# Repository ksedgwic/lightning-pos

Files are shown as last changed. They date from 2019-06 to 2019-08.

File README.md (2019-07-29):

Lightning Pay Station
================================================================

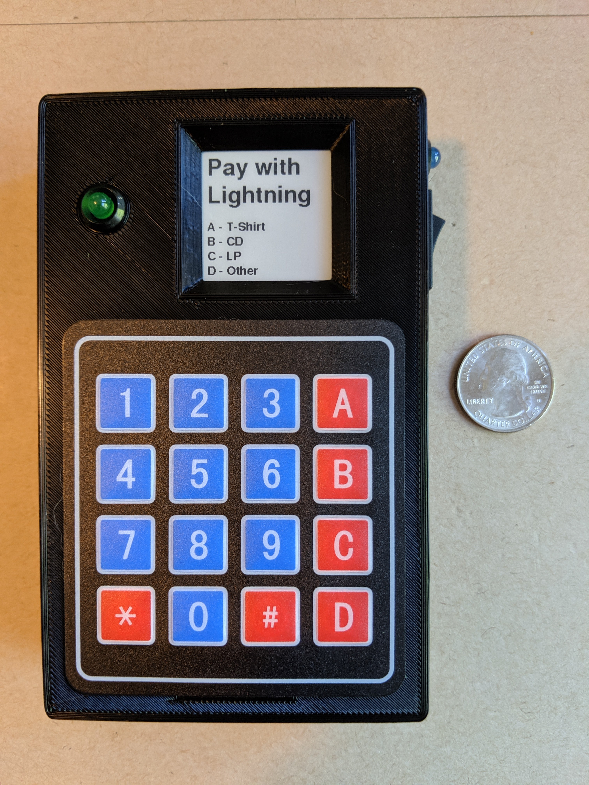
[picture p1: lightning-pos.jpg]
Lightning Pay Station


Many thanks to [arcbtc](https://github.com/arcbtc), his 
[OpenNode Tutorial](https://github.com/arcbtc/bitcoin2019conf)
and gift of working kit totally bootstrapped this project.

The goal of this project is to build an inexpensive open source
point-of-sale terminal for lightning network payments.  The
terminal can connect to:
1. OpenNode Accounts
2. BTCPay's Invoice API
3. LND's REST Interface

The unit is designed to be attached to a wall or used standalone on a
counter.  It contains an internal battery and can operate for many
hours on battery power.  It requires a WiFi network to connect to the
invoice api.

The current software supports three "presets" for commonly purchased
item descriptions and prices and an "other" item with a dynamically
specified price.

The [Parts List](parts-list.md) describes all needed parts.

The case can be 3D printed from the provided STL files.

The [Assembly Instructions](assembly.md) show how to put it together.

## Create Account at OpenNode

Create an account at [OpenNode](https://app.opennode.co/join/fad8135d-ed69-4811-840c-bfa4e30df563).

Navigate to Settings -> Integrations -> API keys.

Select "Add key" and set the permissions to "Invoices".  Make a note
of the Invoice API key string.

## Setup Arduino IDE

Start with the [SparkFun Software Setup
Directions](https://learn.sparkfun.com/tutorials/esp32-thing-plus-hookup-guide#software-setup)
to install the IDE and establish basic functionality.

Next, from "Manage Libraries" install:
```
* GxEPD2
* Arduinojson
* QRCode
* AdaFruit GFX
* Keypad
* base64
```

Install pyserial:

    pip install --user pyserial

## Compile and Upload

To configure the PoS terminal please copy config.h.template to
config.h and edit as appropriate for your setup.

Press the "Upload" button to compile and load into the Arduino.

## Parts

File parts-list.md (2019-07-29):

Lightning PoS Parts List
================================================================

| Description | Quantity | Price |
|---|---:|---:|
| [MH-ET LIVE 1.54 Inch Epaper Module](https://www.aliexpress.com/item/32915952925.html) | 1 | $12.00 |
| [16 Key Membrane Switch Keypad](https://www.aliexpress.com/item/32874565775.html) | 1 |  $0.54 |
| [SparkFun ESP32 Thing Plus](https://www.sparkfun.com/products/14689) | 1 | $20.95 |
| [Lithium Ion Battery - 2Ah](https://www.sparkfun.com/products/13855) | 1 | $12.95 |
| [LED - Basic Green 5mm](https://www.sparkfun.com/products/9592) | 1 |  $0.35 |
| [LED - Basic Blue 5mm](https://www.sparkfun.com/products/11372) | 1 |  $0.55 |
| [LED Holder - 5mm](https://www.sparkfun.com/products/11840) | 2 |  $1.00 |
| [Jumper Wires](https://www.sparkfun.com/products/12796) | 1 |  $1.95 |
| [Break Away Male Headers - Right Angle](https://www.sparkfun.com/products/553) | 1 |  $1.95 |
| [Rocker Switch](https://www.pololu.com/product/1406) | 1 |  $0.75 |
| [Flat Head Thread-Forming Screws](https://www.mcmaster.com/96068a153) | 4 |  $0.23 |
| [Phillips Rounded Head Thread-Forming Screws](https://www.mcmaster.com/99461A710) | 6 |  $1.41 |
| [Push-In Bumpers](https://www.mcmaster.com/9544k12) | 4 |  $0.30 |
| [6 ft USB A to MicroUSB B Cable](https://www.amazon.com/gp/product/B001AR6MI6) | 1 |  $6.39 |
| 3D Printed Case | 1 | |
| **TOTAL** | | $61.32 |

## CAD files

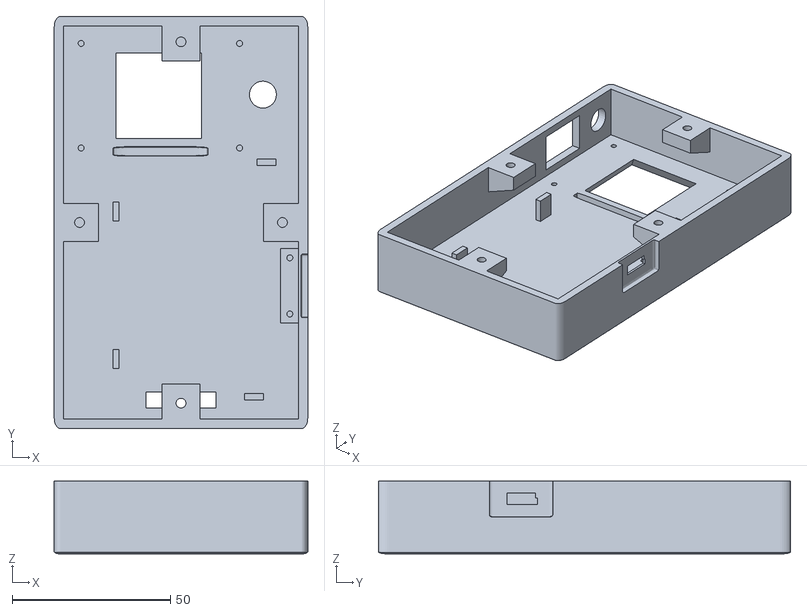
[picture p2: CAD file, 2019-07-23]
case-case.stl
80.0 x 130.0 x 23.0

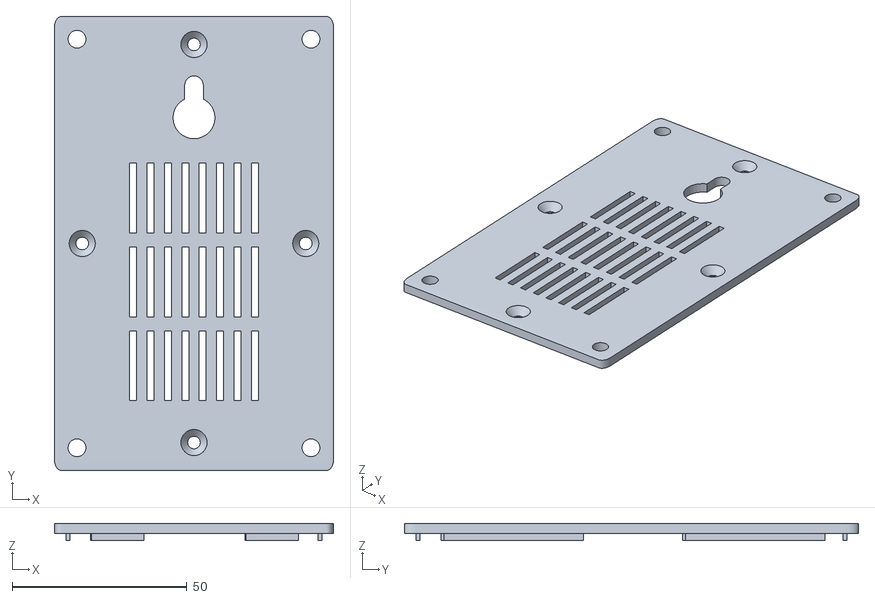
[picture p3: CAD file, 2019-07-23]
case-cover.stl
80.0 x 130.0 x 5.00

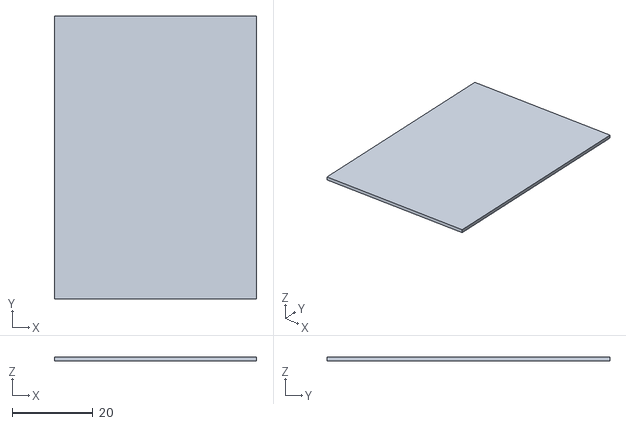
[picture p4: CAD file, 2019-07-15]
case-shield.stl
50.0 x 70.0 x 1.00

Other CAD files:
case.blend

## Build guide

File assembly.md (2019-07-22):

#### References

[ESP32 Datasheet](https://cdn.sparkfun.com/assets/learn_tutorials/8/5/2/ESP32ThingPlus_GraphicalDatasheet.pdf)

#### Split Wires

Start with this:

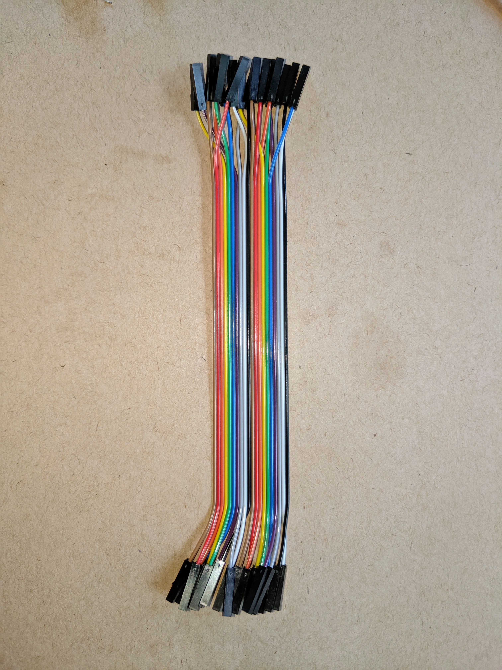
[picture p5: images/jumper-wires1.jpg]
Jumper Wires 1


End up with this:

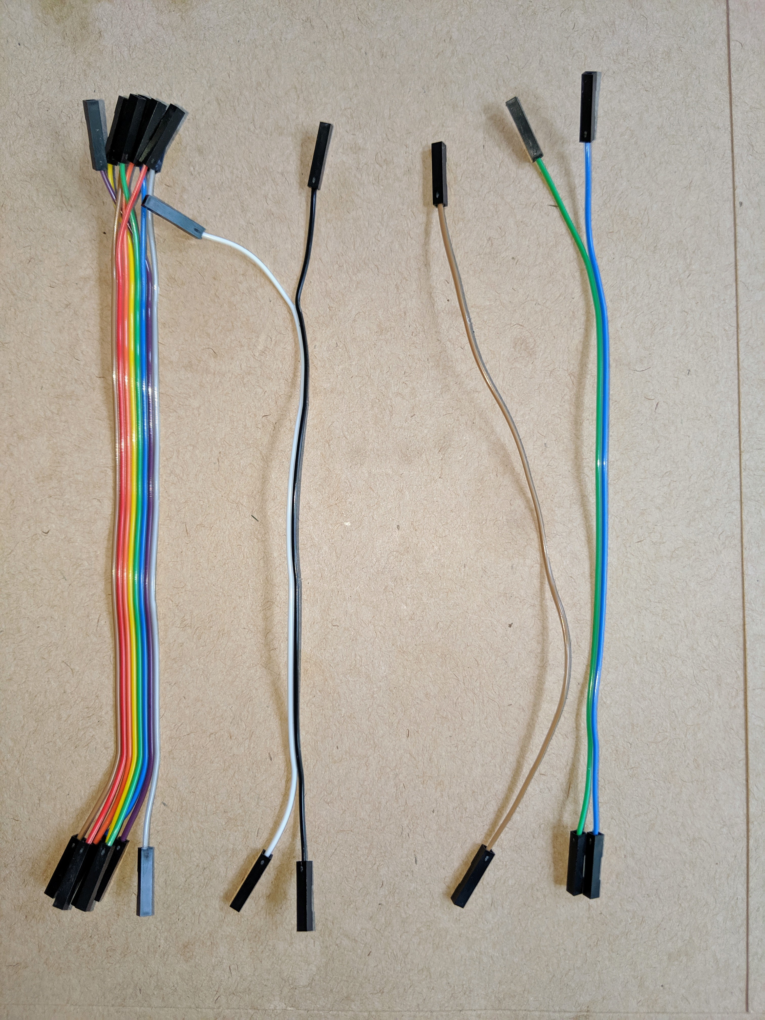
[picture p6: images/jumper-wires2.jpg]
Jumper Wires 2


#### Switch Harness

1. Separate (pull apart) a black/white pair from the jumper wires.
   Cut this pair in the middle and strip 1cm of the ends on one of the
   halves.

2. Separate a brown wire from the jumper wires. Cut this wire in the
   middle and strip 1cm of the ends on both halves.
   
3. Twist the stripped black lead together with the stripped brown
   leads and solder to post "1b" on the switch (under the "1" part of
   the switch).

4. Solder the white lead to the center post of the switch.

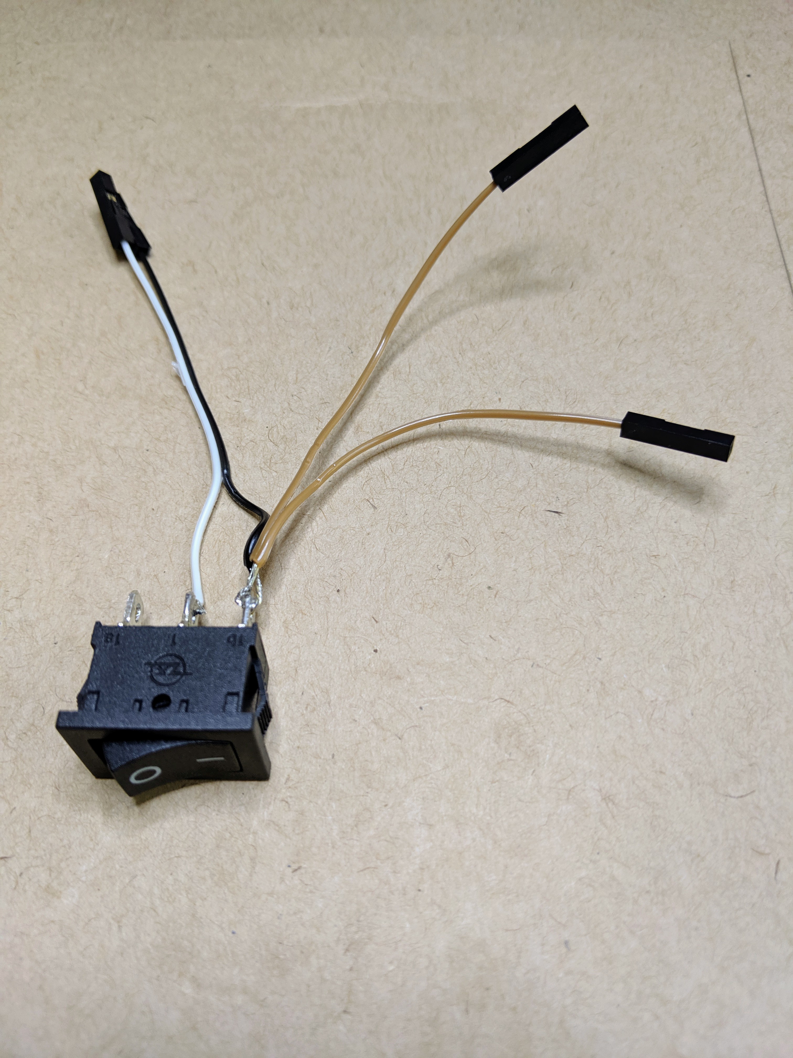
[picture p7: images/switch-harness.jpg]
Switch Harness


#### Display Header

The display comes with an appropriately sized right-angle header.

1. Solder the right-angle header onto the display.  The pins should
   face inward, towards the circuitry under the display.
   
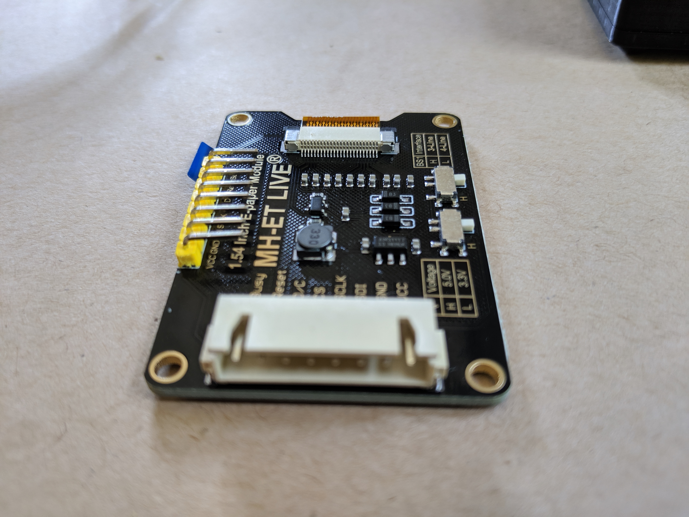
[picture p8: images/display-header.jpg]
Display Header


#### ESP32 Headers

1. Break the right-angle header stock into a 12 pin piece and a 16 pin
   piece.
   
2. Solder the headers onto the top of the ESP32 module with the pins
   facing away from the board.
   
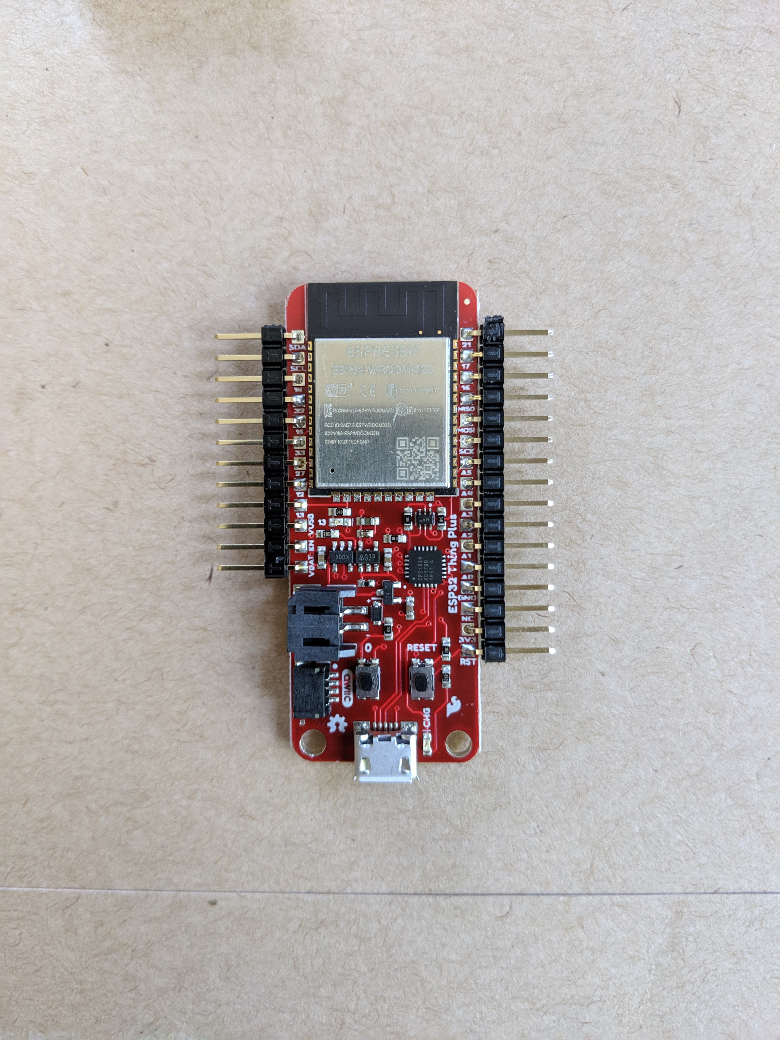
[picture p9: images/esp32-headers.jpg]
ESP32 Headers


#### ESP32 Short

1. Solder a piece of wire between the GND and NC pins on the ESP32.

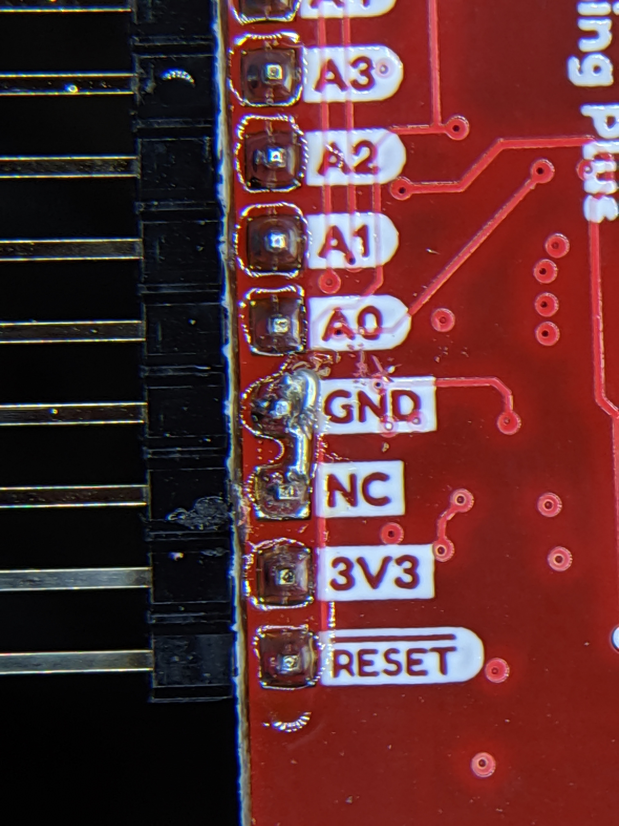
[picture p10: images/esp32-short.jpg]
ESP32 Short


#### Display Harness

1. Separate eight wires from the jumper wires.  It's best if you can
   match the colors in the picture.
   
2. Attach the wires to the display module as shown.

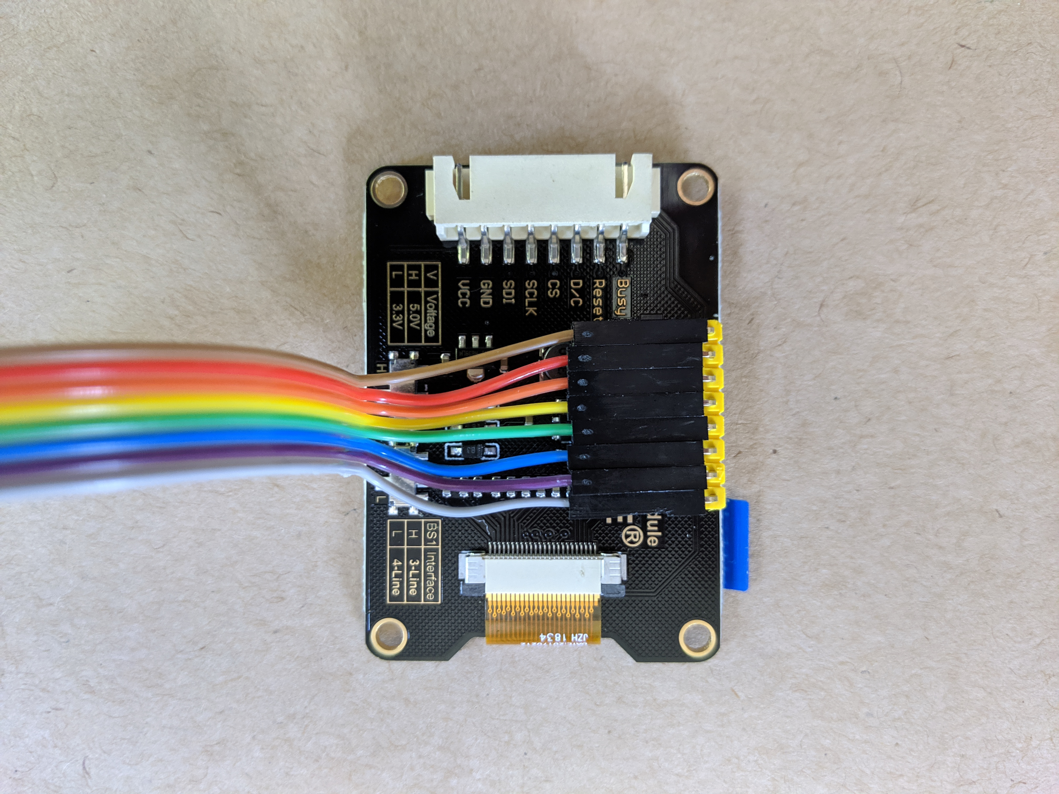
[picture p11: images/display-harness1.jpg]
Display Harness 1


3. Attach the other ends of the wires to the ESP32 module as shown in
   the picture.
   
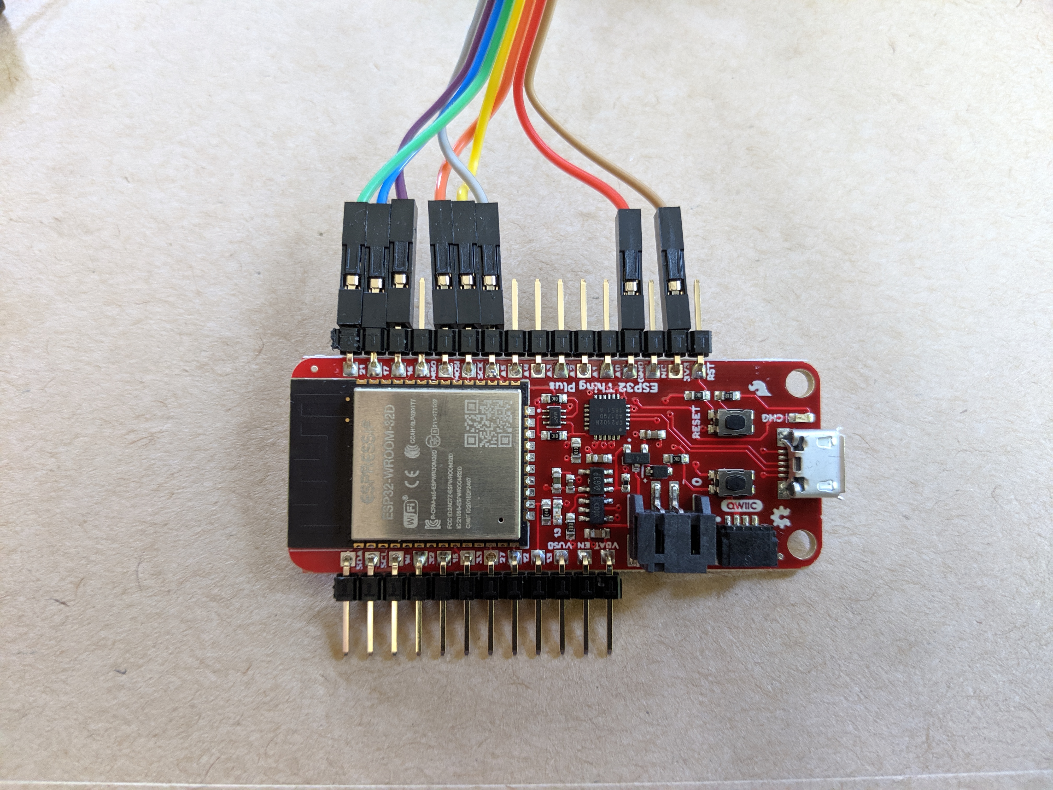
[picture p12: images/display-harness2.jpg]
Display Harness 2


#### Led Wires

1. Separate a blue and green pair from the jumper wires.  Split the
   pair most of the way to one side.
   
2.  Attach the non-split side of the pair to the ESP32 module as
    shown.

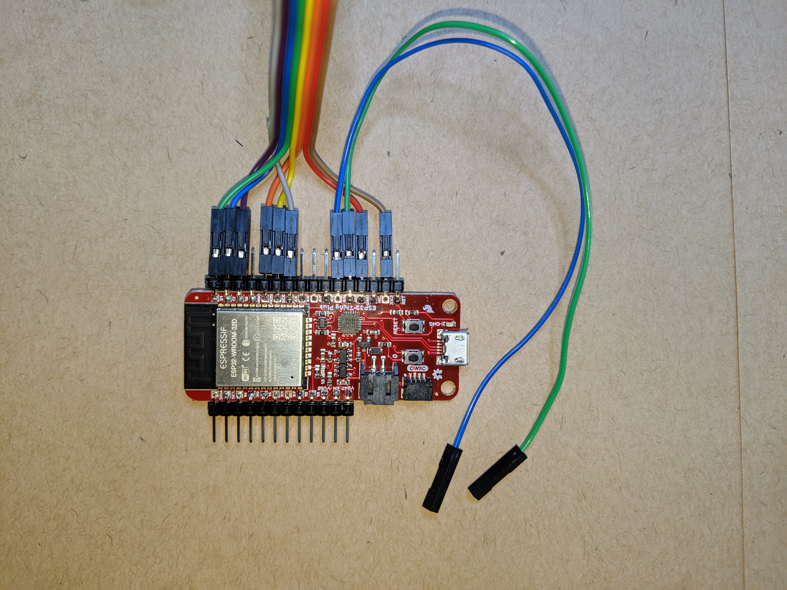
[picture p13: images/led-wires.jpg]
LED Wires


#### Keypad

1. Insert the keypad connector through the slot at the bottom of the
   case front.
   
2. Peel the adhesive cover off the back of the keypad and press it
   into place on the case as shown.
   
Keypad

#### Attach Display to Case

1. Gently screw the display in place in the case.  DO NOT OVERTIGHTEN
   SCREWS.
   
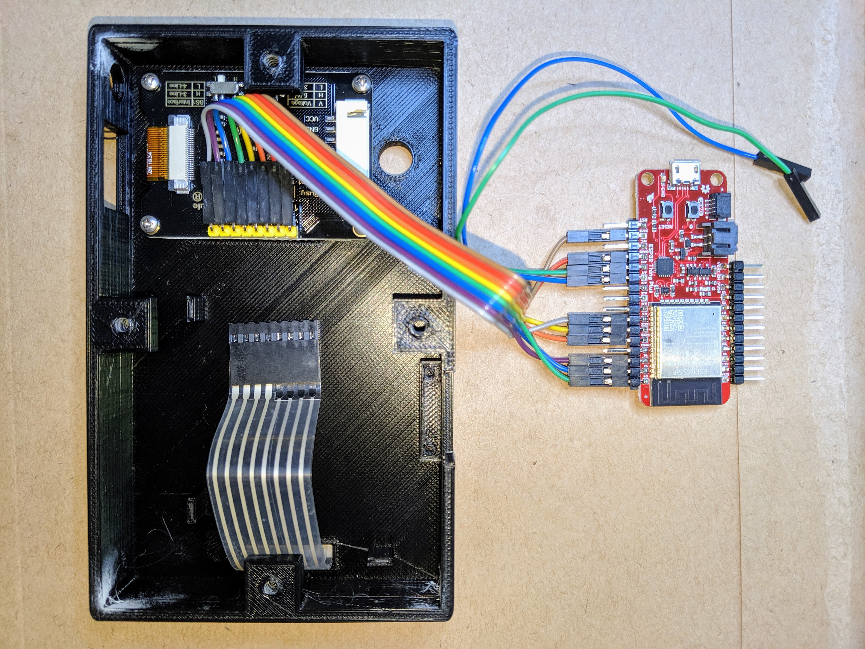
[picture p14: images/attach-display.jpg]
Attach Display


#### Attach LEDs to Case

1. Insert the blue led into a led holder and snap into place in the
   hole in the side of the case (above where the power switch will go.
   It's helpful if the led's leads are horizontally oriented.
   
2. Insert the green led into a led holder and snap into place in the
   hole in the front of the case.  Again it's helpful if the leads are
   oriented horizontally.
   
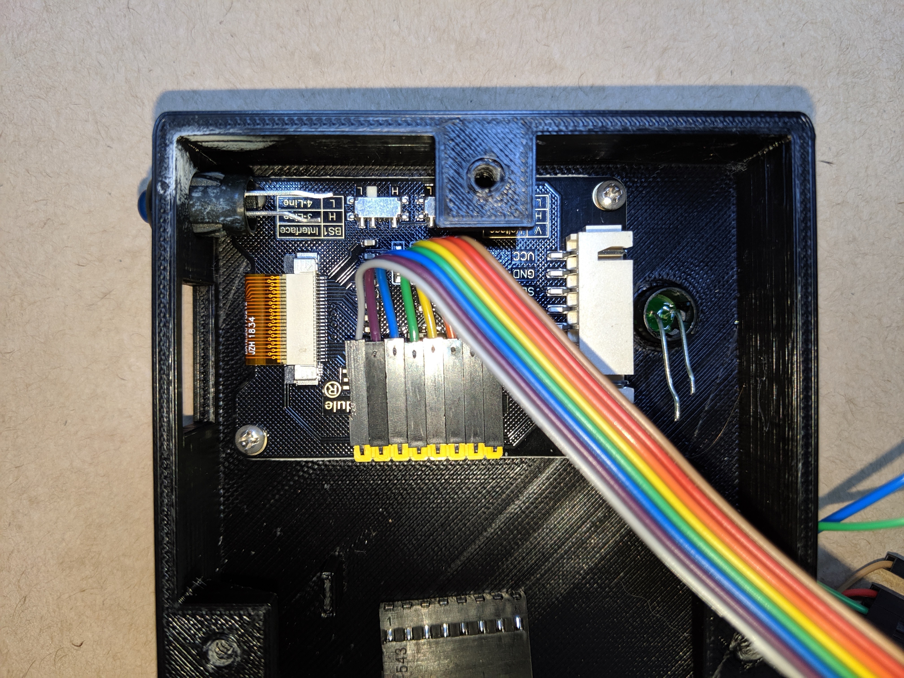
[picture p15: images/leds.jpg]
LEDs


#### Attach the Switch to Case

1. Snap the switch into place in the case.  Orient the switch so the
   "1" side is towards the top of the case.
   
2. Connect the white and black switch leads to the ESP32 module as
   shown.
   
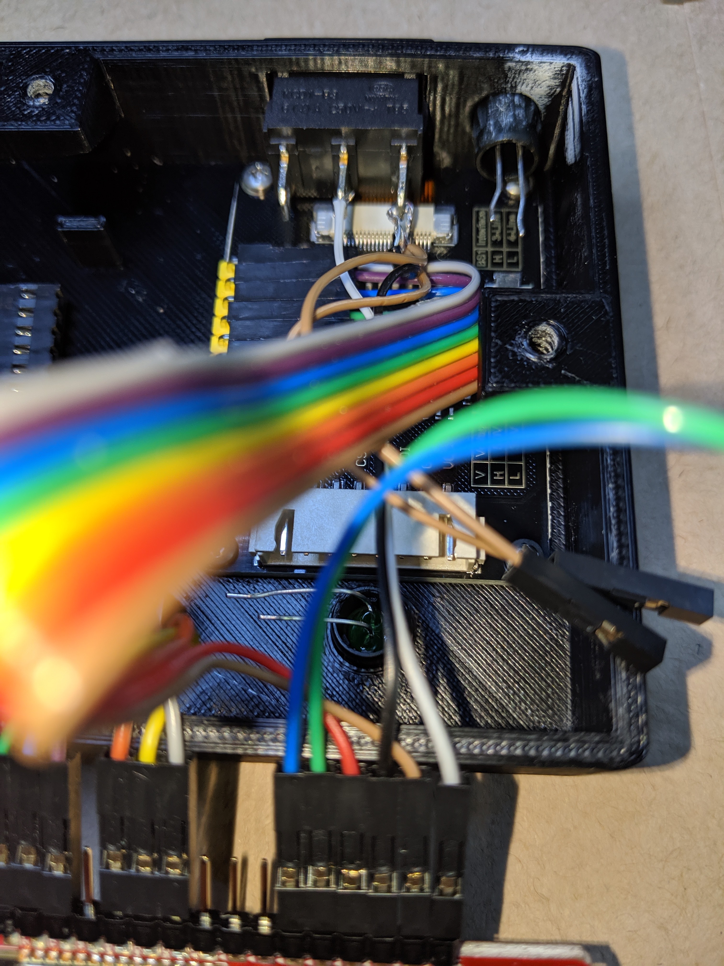
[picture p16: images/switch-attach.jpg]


#### Insert Battery

1. Place the battery into the guides as shown.

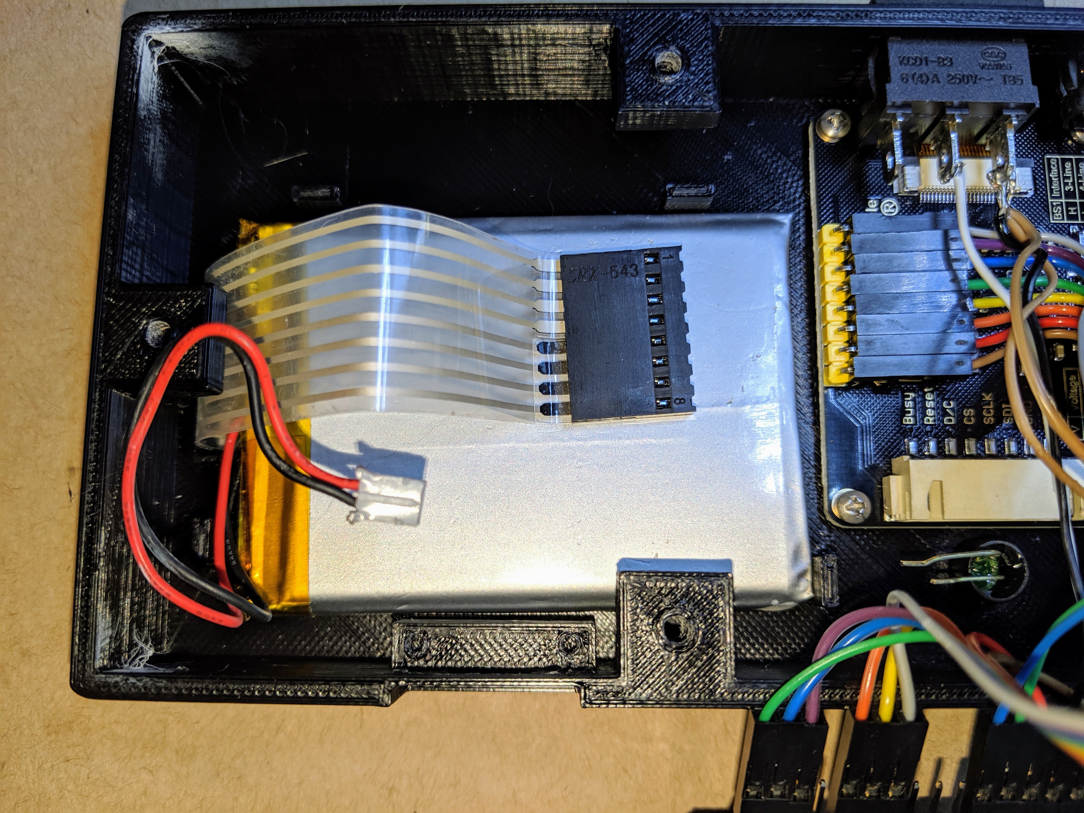
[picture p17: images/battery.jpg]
Battery


#### Battery Shield

1. Place the shield on top of the battery in the guides as shown.

The shield prevents the ESP32 module from damaging the surface of the
battery.

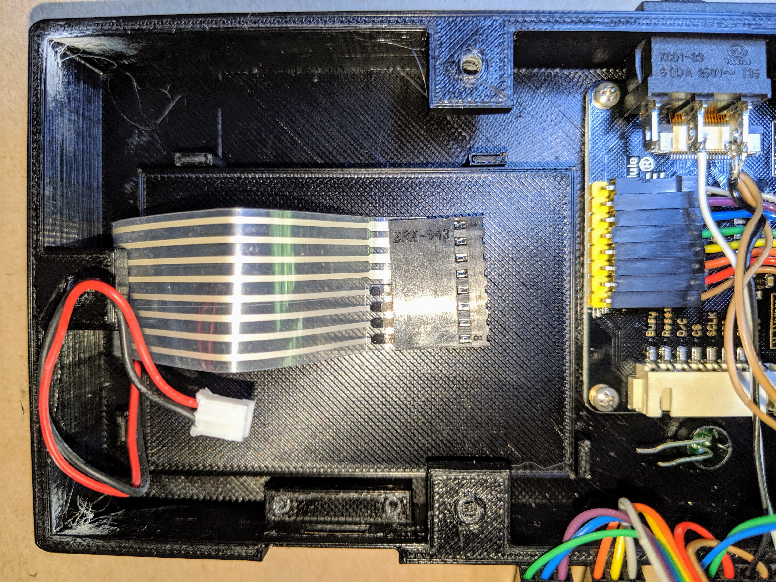
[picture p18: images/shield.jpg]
Shield


#### Keypad Connector

1. Connect the keypad connector to the ESP32 as shown. Note that the
   connector fits "one pin in" from the end of the header.

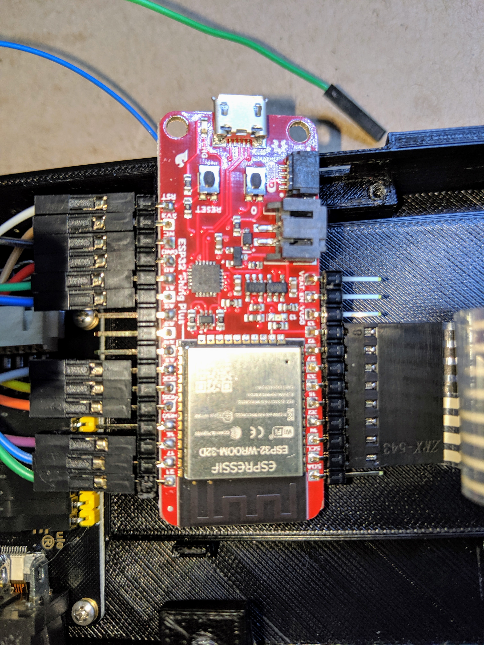
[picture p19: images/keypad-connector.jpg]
Keypad Connector


#### Attach ESP32 to Case

1. Fit the ESP32 into is mounting location.  Attach with screws.  DO
   NOT OVERTIGHTEN THE SCREWS.

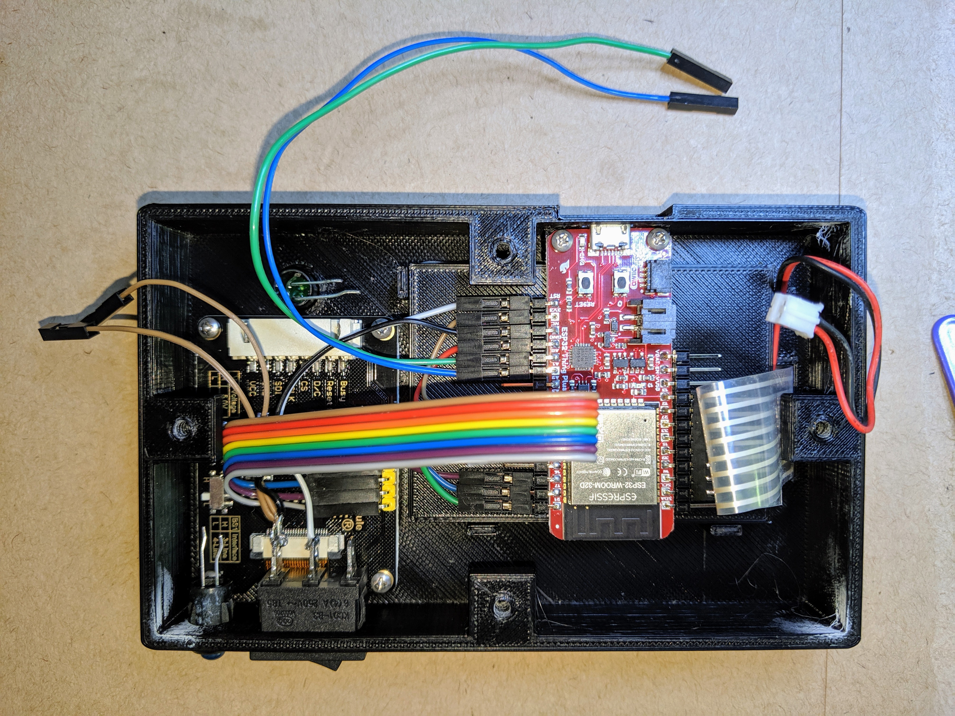
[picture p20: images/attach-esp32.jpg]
Attach ESP32


#### Connect LEDS

1. Connect the green wire to the longer lead of the green led.

2. Connect the blue wire to the longer lead of the blue led.

3. Connect one of the brown wires to the shorter lead of the green led.

4. Connect the other brown wires to the shorter lead of the blue led.

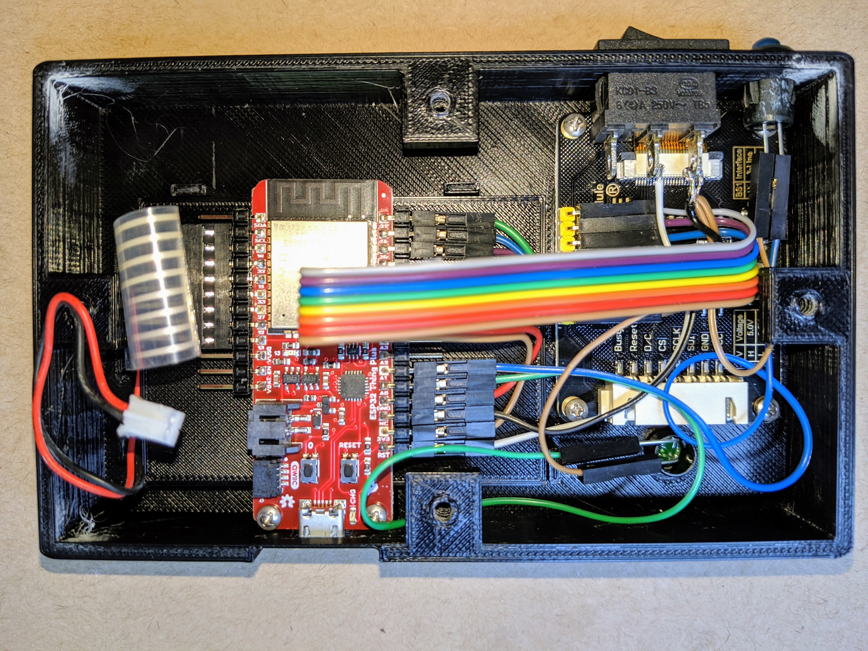
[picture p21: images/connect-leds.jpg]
Connect LEDs


#### Connect Battery

1. Carefully connect the battery to the ESP32.  Support the ESP32 as
   you insert the connector to avoid stressing the attachment screws.
   
**IMPORTANT** - Always disconnect the battery first when working on
the inside of the terminal to avoid damaging the cicuits.

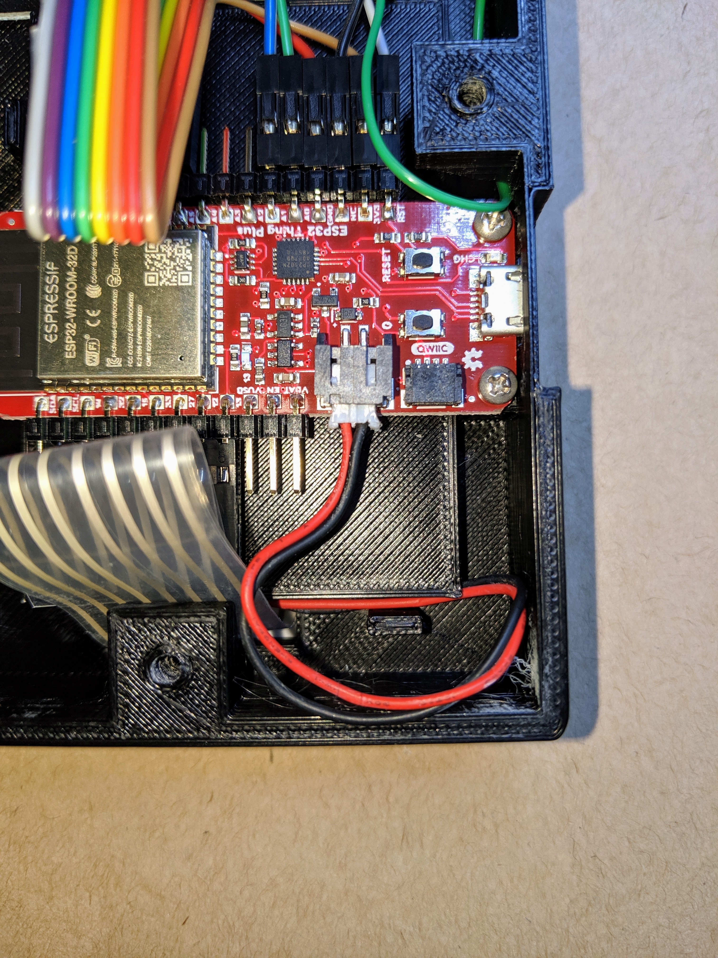
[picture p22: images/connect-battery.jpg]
Connect Battery


#### That's It!

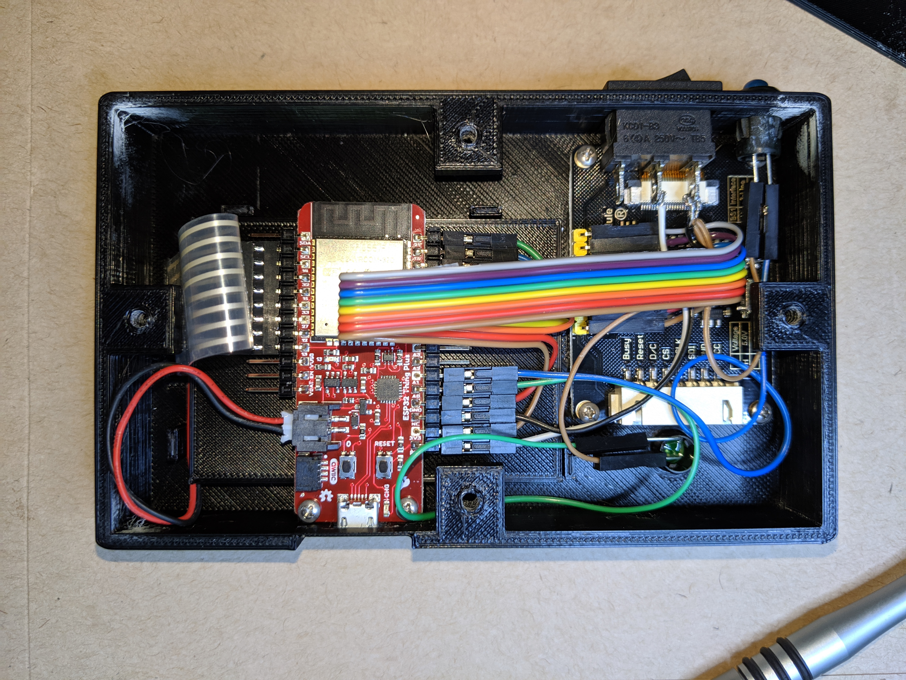
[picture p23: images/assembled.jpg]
Assembled


#### Attach the Cover

1. Press the rubber feet into the back cover.

2. Attach the cover to the back with the screws.

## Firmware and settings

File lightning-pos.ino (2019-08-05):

// Copyright 2019 Bonsai Software, Inc.  All Rights Reserved.

/**
 *  Flux Capacitor PoS Terminal - a point of sale terminal which can
 *  accept bitcoin via lightning network
 *
 *  Epaper PIN MAP: [
 *      VCC - 3.3V
 *      GND - GND
 *      SDI - GPIO18
 *     SCLK - GPIO5
 *       CS - GPIO21
 *      D/C - GPIO17
 *    Reset - GPIO16
 *     Busy - GPIO4
 *  ]
 *
 *  Keypad Matrix PIN MAP: [
 *     Pin8 - GPIO13
 *        7 - GPIO12
 *        6 - GPIO27
 *        5 - GPIO33
 *        4 - GPIO15
 *        3 - GPIO32
 *        2 - GPIO14
 *     Pin1 - GPIO22
 *  ]
 *
 *  BLUE LED PIN MAP: [
 *    POS (long leg)  - GPIO25
 *    NEG (short leg) - GND
 *  ]
 *
 *  GREEN LED PIN MAP: [
 *    POS (long leg)  - GPIO26
 *    NEG (short leg) - GND
 *  ]
 *
 */

#include <WiFiClientSecure.h>

#include <ArduinoJson.h> //Use version 5.3.0!
#include <GxEPD2_BW.h>
#include <qrcode.h>
#include <string.h>

#include <Keypad.h>

#include <Fonts/FreeSansBold18pt7b.h>
#include <Fonts/FreeSansBold9pt7b.h>
#include <Fonts/FreeSansBold12pt7b.h>

struct wifi_conf_t {
    String ssid;
    String pass;
};

struct preset_t {
    String title;
    float price;
};

#include "config.h"

// fiat/btc price
double g_rate;
unsigned long g_rate_tstamp = 0;

struct payreq_t {
    String id;
    String invoice;
};

//Set keypad
const byte rows_ = 4;
const byte cols_ = 4;
char keys_[rows_][cols_] = {
                         {'1','2','3','A'},
                         {'4','5','6','B'},
                         {'7','8','9','C'},
                         {'*','0','#','D'}
};
byte rowPins_[rows_] = {13, 12, 27, 33};
byte colPins_[cols_] = {15, 32, 14, 22};
Keypad g_keypad = Keypad( makeKeymap(keys_), rowPins_, colPins_, rows_, cols_ );

GxEPD2_BW<GxEPD2_154, GxEPD2_154::HEIGHT> g_display(
        GxEPD2_154(
                   /*CS=*/   21,
                   /*DC=*/   17,
                   /*RST=*/  16,
                   /*BUSY=*/ 4));

char g_keybuf[20];
unsigned long g_sats;
double g_fiat;
int g_preset = -1;

void setup() {
    pinMode(25, OUTPUT);	// Blue LED
    digitalWrite(25, HIGH);
    
    g_display.init(115200);

    displayText(20, 100, "Loading ...");

    Serial.begin(115200);

    while (!Serial);
    
    setupNetwork();
    Serial.println("connected");

    pinMode(26, OUTPUT);	// Green LED

    // Refresh the exchange rate.
    checkrate();
}

void loop() {
    g_preset = -1;
    displayMenu();
    while (g_preset == -1) {
        char key = g_keypad.getKey();
        switch (key) {
        case NO_KEY:
            break;
        case 'A':
        case 'B':
        case 'C':
        case 'D':
            g_preset = key - 'A';
            break;
        default:
            break;
        }
    }

    memset(g_keybuf, 0, sizeof(g_keybuf));

    // Collect amount, if none return to main menu.
    if (!keypadamount()) {
        return;
    }
    Serial.printf("pay %d %f %lu\n", g_preset, g_fiat, g_sats);

    payreq_t payreq;
    if (cfg_invoice_api == "OPN") {
        payreq = opn_createinvoice();
    } else if (cfg_invoice_api == "BTP") {
        payreq = btp_createinvoice();
    } else if (cfg_invoice_api == "LND") {
        payreq = lnd_createinvoice();
    }
    
    if (payreq.id == "") {
        return;
    }

    if (!displayQR(&payreq)) {
        return;
    }

    waitForPayment(&payreq);
}

void setupNetwork() {
    int nconfs = sizeof(cfg_wifi_confs) / sizeof(wifi_conf_t);
    Serial.printf("scanning %d wifi confs\n", nconfs);
    int ndx = 0;
    while (true) {
        const char* ssid = cfg_wifi_confs[ndx].ssid.c_str();
        const char* pass = cfg_wifi_confs[ndx].pass.c_str();

        Serial.printf("trying %s\n", ssid);
        displayText(10, 100, String("Trying ") + ssid);

        WiFi.begin(ssid, pass);

        // Poll the status for a while.
        for (int nn = 0; nn < 50; ++nn) {
            if (WiFi.status() == WL_CONNECTED) {
                Serial.printf("connected to %s\n", ssid);
                return;
            }
            delay(100);
        }

        // Try the next access point, wrap.
        if (++ndx == nconfs) {
            ndx = 0;
        }
    }
}

void displayText(int col, int row, String txt) {
    g_display.firstPage();
    do
    {
        g_display.setRotation(1);
        g_display.setPartialWindow(0, 0, 200, 200);
        g_display.fillScreen(GxEPD_WHITE);
        g_display.setFont(&FreeSansBold9pt7b);
        g_display.setTextColor(GxEPD_BLACK);
        g_display.setCursor(col, row);
        g_display.println(txt);
    }
    while (g_display.nextPage());
}

void displayMenu() {
    Serial.printf("displayMenu\n");
    g_display.firstPage();
    do
    {
        g_display.setRotation(1);
        g_display.setPartialWindow(0, 0, 200, 200);
        g_display.fillScreen(GxEPD_WHITE);
        g_display.setFont(&FreeSansBold18pt7b);
        g_display.setTextColor(GxEPD_BLACK);
        g_display.setCursor(0, 37);
        g_display.println(cfg_title[0]);
        g_display.println(cfg_title[1]);
        g_display.setFont(&FreeSansBold9pt7b);
        for (int ndx = 0; ndx < 4; ++ndx) {
            char but = 'A' + ndx;
            g_display.printf("  %c - %s\n",
                             but, cfg_presets[ndx].title.c_str());
        }
    }
    while (g_display.nextPage());
}

int applyPreset() {
    checkrate();
    String centstr = String(long(cfg_presets[g_preset].price * 100));
    memset(g_keybuf, 0, sizeof(g_keybuf));
    memcpy(g_keybuf, centstr.c_str(), centstr.length());
    Serial.printf("applyPreset %d g_keybuf=%s\n", g_preset, g_keybuf);
    displayAmountPage();
    showPartialUpdate(g_keybuf);
    return centstr.length();
}

//Function for keypad
unsigned long keypadamount() {
    // Refresh the exchange rate.
    applyPreset();
    int checker = 0;
    while (checker < sizeof(g_keybuf)) {
        char key = g_keypad.getKey();
        switch (key) {
        case NO_KEY:
            break;
        case '#':
            displayText(10, 100, "Generating QR ...");
            return true;
        case '*':
            if (cfg_presets[g_preset].price != 0.00) {
                // Pressing '*' with preset value returns to main menu.
                return false;
            } else {
                // Otherwise clear value and stay on screen.
                checker = applyPreset();
                break;
            }
        case 'A':
        case 'B':
        case 'C':
        case 'D':
            g_preset = key - 'A';
            checker = applyPreset();
            break;
        default:
            g_keybuf[checker] = key;
            checker++;
            Serial.printf("g_keybuf=%s\n", g_keybuf);
            showPartialUpdate(g_keybuf);
            break;
        }
    }
    // Only get here when we overflow the g_keybuf.
    return false;
}

void displayAmountPage() {
    g_display.firstPage();
    do
    {
        g_display.setRotation(1);
        g_display.setPartialWindow(0, 0, 200, 200);
        g_display.fillScreen(GxEPD_WHITE);
        g_display.setFont(&FreeSansBold12pt7b);
        g_display.setTextColor(GxEPD_BLACK);

        g_display.setCursor(0, 30);
        g_display.println(" " + cfg_presets[g_preset].title);

        g_display.setCursor(0, 60);
        if (cfg_presets[g_preset].price == 0.00) {
            g_display.println(" Enter Amount");
        } else {
            g_display.println();
        }
        
        g_display.setCursor(0, 95);
        g_display.println(" " + cfg_opn_currency.substring(3) + ": ");
        g_display.println(" Sats: ");

        g_display.setFont(&FreeSansBold9pt7b);
        g_display.setCursor(0, 160);
        if (cfg_presets[g_preset].price == 0.00) {
            g_display.println("   Press * to clear");
        } else {
            g_display.println("   Press * to cancel");
        }
        g_display.println("   Press # to submit");

    }
    while (g_display.nextPage());
}

// Display current amount
void showPartialUpdate(String centsStr) {

    g_fiat = centsStr.toFloat() / 100.0;

    // Convert fiat to sats, add 0.9999 and truncate (ceiling)
    g_sats = long((g_fiat * 100e6 / g_rate) + 0.9999);

    g_display.firstPage();
    do
    {
        g_display.setRotation(1);
        g_display.setFont(&FreeSansBold12pt7b);
        g_display.setTextColor(GxEPD_BLACK);

        // g_display.fillRect(box_x, box_y, box_w, box_h, GxEPD_WHITE);
        g_display.setPartialWindow(70, 75, 120, 20);
        g_display.setCursor(70, 95);
        g_display.print(g_fiat);

    }
    while (g_display.nextPage());

    g_display.firstPage();
    do
    {
        g_display.setRotation(1);
        g_display.setFont(&FreeSansBold12pt7b);
        g_display.setTextColor(GxEPD_BLACK);

        // g_display.fillRect(box_x, box_y, box_w, box_h, GxEPD_WHITE);
        g_display.setPartialWindow(70, 105, 120, 20);
        g_display.setCursor(70, 125);
        g_display.print(g_sats);

    }
    while (g_display.nextPage());
}
    
bool displayQR(payreq_t * payreqp) {
    // This code from https://github.com/arcbtc/koopa/blob/master/main.ino
    
    // auto detect best qr code size
    int qrSize = 10;
    int ec_lvl = 0;
    int const sizes[18][4] = {
                        /* https://github.com/ricmoo/QRCode */
                        /* 1 */ { 17, 14, 11, 7 },
                        /* 2 */ { 32, 26, 20, 14 },
                        /* 3 */ { 53, 42, 32, 24 },
                        /* 4 */ { 78, 62, 46, 34 },
                        /* 5 */ { 106, 84, 60, 44 },
                        /* 6 */ { 134, 106, 74, 58 },
                        /* 7 */ { 154, 122, 86, 64 },
                        /* 8 */ { 192, 152, 108, 84 },
                        /* 9 */ { 230, 180, 130, 98 },      // OPN:0 LND:0 good
                        /* 10 */ { 271, 213, 151, 119 },    // BTP:0 OPN:1 good
                        /* 11 */ { 321, 251, 177, 137 },
                        /* 12 */ { 367, 287, 203, 155 },    // BTP:1 bad
                        /* 13 */ { 425, 331, 241, 177 },    // BTP:2 meh
                        /* 14 */ { 458, 362, 258, 194 },
                        /* 15 */ { 520, 412, 292, 220 },
                        /* 16 */ { 586, 450, 322, 250 },
                        /* 17 */ { 644, 504, 364, 280 },
    };
    int len = payreqp->invoice.length();
    for(int ii=0; ii<17; ii++){
        qrSize = ii+1;
        if(sizes[ii][ec_lvl] > len){
            break;
        }
    }

    Serial.printf("len = %d, ec_lvl = %d, qrSize = %d\n",
                  len, ec_lvl, qrSize);

    // Create the QR code
    QRCode qrcode;
    uint8_t qrcodeData[qrcode_getBufferSize(qrSize)];
    qrcode_initText(&qrcode, qrcodeData, qrSize, ec_lvl,
                    payreqp->invoice.c_str());
    
    Serial.printf("saw qr mode = %d\n", qrcode.mode);

    int width = 17 + 4*qrSize;
    int scale = 190/width;
    int padding = (200 - width*scale)/2;

    g_display.firstPage();
    do
    {
        g_display.setPartialWindow(0, 0, 200, 200);
        g_display.fillScreen(GxEPD_WHITE);
        // for every pixel in QR code we draw a rectangle with size `scale`
        for (uint8_t y = 0; y < qrcode.size; y++) {
            for (uint8_t x = 0; x < qrcode.size; x++) {
                if(qrcode_getModule(&qrcode, x, y)){
                    g_display.fillRect(padding+scale*x,
                                       padding+scale*y,
                                       scale, scale, GxEPD_BLACK);
                }
            }
        }
    }
    while (g_display.nextPage());
}

// Handle outcome
void waitForPayment(payreq_t * payreqp) {
    int counta = 0;
    int ispaid = 0;
    if (cfg_invoice_api == "OPN") {
        ispaid = opn_checkpayment(payreqp->id);
    } else if (cfg_invoice_api == "BTP") {
        ispaid = btp_checkpayment(payreqp->id);
    } else if (cfg_invoice_api == "LND") {
        ispaid = lnd_checkpayment(payreqp->id);
    }
    
    while (counta < 40) {
        switch (ispaid) {
        case -1: // error while checking, not paid after reconnect
            // Need to redisplay the qr code
            displayQR(payreqp);
            // fallthrough on purpose
        case 0: // not paid yet
            // Delay, checking for abort.
            for (int nn = 0; nn < 10; ++nn) {
                if (g_keypad.getKey() == '*') {
                    return;
                }
                delay(10);
            }
            if (cfg_invoice_api == "OPN") {
                ispaid = opn_checkpayment(payreqp->id);
            } else if (cfg_invoice_api == "BTP") {
                ispaid = btp_checkpayment(payreqp->id);
            } else if (cfg_invoice_api == "LND") {
                ispaid = lnd_checkpayment(payreqp->id);
            }
            counta++;
            break;
        case 1: // paid
            // Display big success message.
            g_display.firstPage();
            do
            {
                g_display.setRotation(1);
                g_display.setPartialWindow(0, 0, 200, 200);
                g_display.fillScreen(GxEPD_WHITE);
                g_display.setFont(&FreeSansBold18pt7b);
                g_display.setTextColor(GxEPD_BLACK);
                g_display.setCursor(50, 80);
                g_display.println("Got it");
                g_display.setCursor(4, 130);
                g_display.println("Thank you!");
            }
            while (g_display.nextPage());
            
            digitalWrite(26, HIGH);
            delay(8000);
            digitalWrite(26, LOW);
            delay(500);
            counta = 40;
            break;
        }
    }
}

///////////////////////////// GET/POST REQUESTS///////////////////////////

void checkrate() {
    // If we have a prior rate that is not wrapped and is fresh enough
    // we're done.
    unsigned long now = millis();
    Serial.printf("checkrate %lu %lu\n", g_rate_tstamp, now);
    if (g_rate_tstamp != 0 &&	/* not first time */
        now > g_rate_tstamp &&	/* wraps after 50 days */
        now - g_rate_tstamp < (10 * 60 * 1000) /* 10 min old */) {
        return;
    }
            
    if (cfg_rate_feed == "OPN") {
        opn_rate();
    } else if (cfg_rate_feed == "BTP") {
        btp_rate();
    } else if (cfg_rate_feed == "CMC") {
        cmc_rate();
    } else {
        Serial.printf("unknown cfg_rate_feed \"%s\"\n", cfg_rate_feed);
        return;	// TODO - what to do here?
    }
    
    g_rate_tstamp = now;
}

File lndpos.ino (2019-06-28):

/**
 *  Flux Capacitor PoS Terminal - a point of sale terminal which can accept bitcoin via lightning network
 *  
 *
 *  Epaper PIN MAP: [VCC - 3.3V, GND - GND, SDI - GPIO23, SCLK - GPIO18, 
 *                   CS - GPIO5, D/C - GPIO17, Reset - GPIO16, Busy - GPIO4]
 *                   
 *  Keypad Matrix PIN MAP: [GPIO12 - GPIO35]
 *
 *  LED PIN MAP: [POS (long leg) - GPIO15, NEG (short leg) - GND]
 *
 */

 
#include <WiFiClientSecure.h>

#include <ArduinoJson.h> //Use version 5.3.0!
#include <GxEPD2_BW.h>
#include <qrcode.h>
#include <string.h>

#include <Keypad.h>

#include <Fonts/FreeSansBold18pt7b.h>
#include <Fonts/FreeSansBold9pt7b.h>
#include <Fonts/FreeSansBold12pt7b.h>


GxEPD2_BW<GxEPD2_154, GxEPD2_154::HEIGHT> display(GxEPD2_154(/*CS=5*/ SS, /*DC=*/ 17, /*RST=*/ 16, /*BUSY=*/ 4));

char wifiSSID[] = "1740Buena";
char wifiPASS[] = "smalltree";

const char* host = "api.opennode.co";
const int httpsPort = 443;
String amount = ""; 
String apikey = "ad4defd1-0e8d-4b04-bc7e-cb3a576d4aae";
String description = "Bonsai PoS"; //invoice description
String hints = "false"; 
String on_currency = "BTCUSD"; //change to your currency ie BTCUSD, BTCEUR, etc
String price;

String data_lightning_invoice_payreq = "";
String data_status = "unpaid";
String data_id = "";
int counta = 0;


//Set other Arduino Strings used
String setoffour = "";
String right = "";
String third = "";
String fourth = "";
String tempfourhex = "";
String line = "";
String line2 = "";
String doublelines = "";
String finalhex = "";
String hexvalues = "";
String result = "";
String PAYMENT = ""; 
String PAYMENTPAID = "true"; 
String response;

//Buffers for Arduino String conversions
char fourbuf[5];
char fourbuff[5];
int tamp = 0;

//Char for holding the QR byte array
unsigned char PROGMEM singlehex[4209];

//Char dictionary for conversion from 1s and 0s
char ref[2][16][5]={
{"0000","0001","0010","0011","0100","0101","0110","0111","1000","1001","1010","1011","1100","1101","1110","1111"},
{"0",   "1",   "2",   "3",   "4",   "5",   "6",   "7",   "8",   "9",   "a",   "b",   "c",   "d",   "e",   "f"}
};

//Set keypad
const byte rows = 4; //four rows
const byte cols = 3; //three columns
char keys[rows][cols] = {
  {'1','2','3'},
  {'4','5','6'},
  {'7','8','9'},
  {'*','0','#'}
};
byte rowPins[rows] = {12, 14, 27, 26}; //connect to the row pinouts of the keypad
byte colPins[cols] = {25, 33, 32}; //connect to the column pinouts of the keypad
Keypad keypad = Keypad( makeKeymap(keys), rowPins, colPins, rows, cols );
int checker = 0;
char maxdig[20];



void setup() {

display.init(115200);

  display.firstPage();
  do
  {
  display.setRotation(1);  
  display.fillScreen(GxEPD_WHITE);
  display.setFont(&FreeSansBold12pt7b);
  display.setTextColor(GxEPD_BLACK);
  display.setCursor(0, 80);
  display.println("Loading :)");
  }
  while (display.nextPage());{
  }

  
Serial.begin(115200); 
           
  WiFi.begin(wifiSSID, wifiPASS);   
  while (WiFi.status() != WL_CONNECTED) {
     Serial.println("connecting");
     delay(100);
     }
     
  Serial.println("connected");

  pinMode(19, OUTPUT);

  ONprice();

}

void loop() {
  
memset(maxdig, 0, 20);
checker = 20;
int counta = 0;

hexvalues = "";


while (*maxdig == 0){
 keypadamount();
 amount = String(maxdig);
}

fetchpayment(amount);

  qrmmaker(data_lightning_invoice_payreq);

     for (int i = 0;  i < line.length(); i+=4){      
        int tmp = i; 
        setoffour = line.substring(tmp, tmp+4); 
       
             for (int z = 0; z < 16; z++){
               if (setoffour == ref[0][z]){
                hexvalues += ref[1][z];
               }
             }
      }

  line = "";

//for loop to build the epaper friendly char singlehex byte array image of the QR
  for (int i = 0;  i < 4209; i++){
     int tmp = i;   
     int pmt = tmp*2; 
     result = "0x" + hexvalues.substring(pmt, pmt+2) + ",";
     singlehex[tmp] = (unsigned char)strtol(hexvalues.substring(pmt, pmt+2).c_str(), NULL, 16);
  }

  

  display.firstPage();
  do
  {
  display.setPartialWindow(0, 0, 200, 200);
  display.fillScreen(GxEPD_WHITE);
  display.drawBitmap( 7, 7, singlehex, 184, 183, GxEPD_BLACK); 
  
  }
  while (display.nextPage());{
  }

 
  checkpayment(data_id);
 while (counta < 30){
  if (data_status == "unpaid"){
    delay(1000);
   checkpayment(data_id);
   counta++;
  }
  else{
  digitalWrite(19, HIGH);
  delay(4000);
  digitalWrite(19, LOW);
  delay(500);
  counta = 30;
    }  
  }
  counta = 0;
  

}


// QR maker function
void qrmmaker(String xxx){

int str_len = xxx.length() + 1; 
char xxxx[str_len];
xxx.toCharArray(xxxx, str_len);


    QRCode qrcode;
    uint8_t qrcodeData[qrcode_getBufferSize(11)];
    qrcode_initText(&qrcode, qrcodeData, 11, 0, xxxx);
  

    int une = 0;
    
    line = "";

    for (uint8_t y = 0; y < qrcode.size; y++) {

        // Each horizontal module
        for (uint8_t x = 0; x < qrcode.size; x++) {
          line += (qrcode_getModule(&qrcode, x, y) ? "111": "000");
        }
        line += "1";
        for (uint8_t x = 0; x < qrcode.size; x++) {
          line += (qrcode_getModule(&qrcode, x, y) ? "111": "000");
        }
        line += "1";
        for (uint8_t x = 0; x < qrcode.size; x++) {
          line += (qrcode_getModule(&qrcode, x, y) ? "111": "000");
        }
        line += "1";    
    }
}





//Function for keypad
void keypadamount(){

display.firstPage();
  do
  {
  display.setRotation(1);
  display.fillScreen(GxEPD_WHITE);
  display.setFont(&FreeSansBold12pt7b);
  display.setTextColor(GxEPD_BLACK);
  display.setCursor(20, 20);
  display.println("Amount then #");
  display.println();
  display.println("Sats: ");
  display.println(on_currency.substring(3) + ": ");
  display.setFont(&FreeSansBold9pt7b);
  display.println(" Press * to clear");

  }
  while (display.nextPage());{
  }

  while (checker < 20){
  
   char key = keypad.getKey();
   
   if (key != NO_KEY){
   String virtkey = String(key);
   
   if (virtkey == "*"){
    memset(maxdig, 0, 20);
    checker = 20;
   }
    
   if (virtkey == "#"){

     display.firstPage();
     do
     {
     display.setRotation(1);
     display.setPartialWindow(0, 0, 200, 200);
     display.fillScreen(GxEPD_WHITE);
     display.setFont(&FreeSansBold12pt7b);
     display.setTextColor(GxEPD_BLACK);
     display.setCursor(20, 20);
     display.println("Processing...");

     }
     while (display.nextPage());{
     }
    Serial.println("Finished");
    checker = 20;
   }
   else{
  
    maxdig[checker] = key;
    checker++;
    Serial.println(maxdig);


    showPartialUpdate(maxdig);
   }
   }

  }
  checker = 0;
}
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

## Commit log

2019-06-29 Swapped USD and sat display rows
    [lightning-pos.ino]
2019-07-02 Fixed display after pay timeout
    [lightning-pos.ino]
2019-07-02 Fixed preset switching bug.
    [lightning-pos.ino]
2019-07-02 Fixed double display of presets
    [lightning-pos.ino]
2019-07-03 Prettied the pin maps
2019-07-03 Fixed up fetchpayment and checkpayment, removed globals.
    [lightning-pos.ino]
2019-07-15 Added design files for the case.
    [case-case.stl, case-cover.stl, case-shield.stl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]
2019-07-15 Tweaked the USB cutout.
    [case-case.stl, case.blend]
2019-07-18 Added blue led placeholder.
2019-07-18 Shrunk height of case. Added blue power led. Better screw and feet placement. Added cover lip.
    [case-case.stl, case-cover.stl, case.blend]
2019-07-20 Added blue led support
2019-07-20 case19: adjusted foot and led hole sizes
    [case-case.stl, case-cover.stl, case.blend]
2019-07-20 assembly.md placeholder
2019-07-20 Added switch harness assembly instructions.
2019-07-20 Added display harness to assembly
2019-07-20 added assembly instructions
2019-07-20 Finished assembly directions.
2019-07-20 Tweaked assembly directions.
2019-07-21 Added jumper-wires to assembly
2019-07-21 Added esp32-short to assembly
2019-07-22 Fixed missing rubber feet in assembly
2019-07-22 Added retries for connection failures. Better error handling.
    [lightning-pos.ino]
2019-07-23 Better error handling for REST calls. Faster polling for payment.
    [lightning-pos.ino]
2019-07-23 case20: shim battery, widen lip beam, adjust pyramid.
    [case-case.stl, case-cover.stl, case.blend]
2019-07-26 Added cert fingerprint "pinning" for service connections.
2019-07-29 fixed 3D printed case parts-list entry
2019-08-04 Improved QR code gen. Fixed error handling of intermittent checkinvoice failures.
    [btcpay.ino, lightning-pos.ino, lnd.ino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]
2019-08-05 Fixed bug w/ auto resize overflow
    [lightning-pos.ino]
